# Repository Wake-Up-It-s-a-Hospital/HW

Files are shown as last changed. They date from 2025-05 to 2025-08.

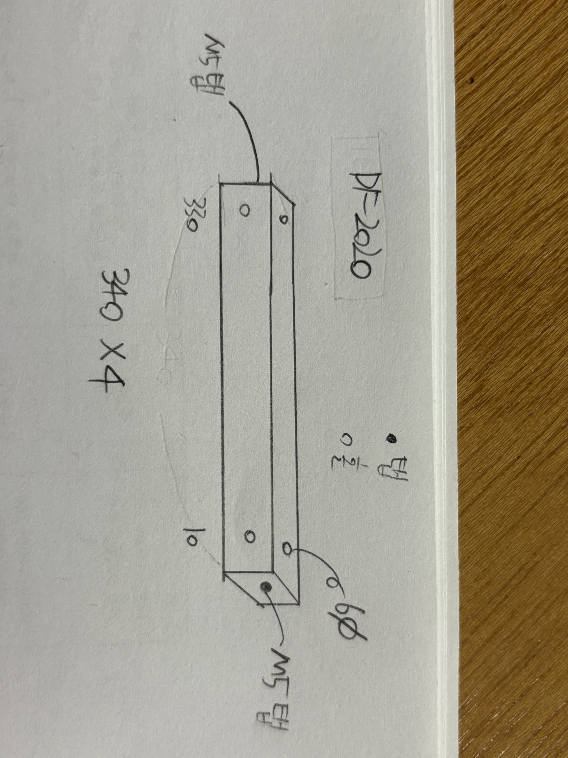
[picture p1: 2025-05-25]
프로파일/1번프로파일.jpg

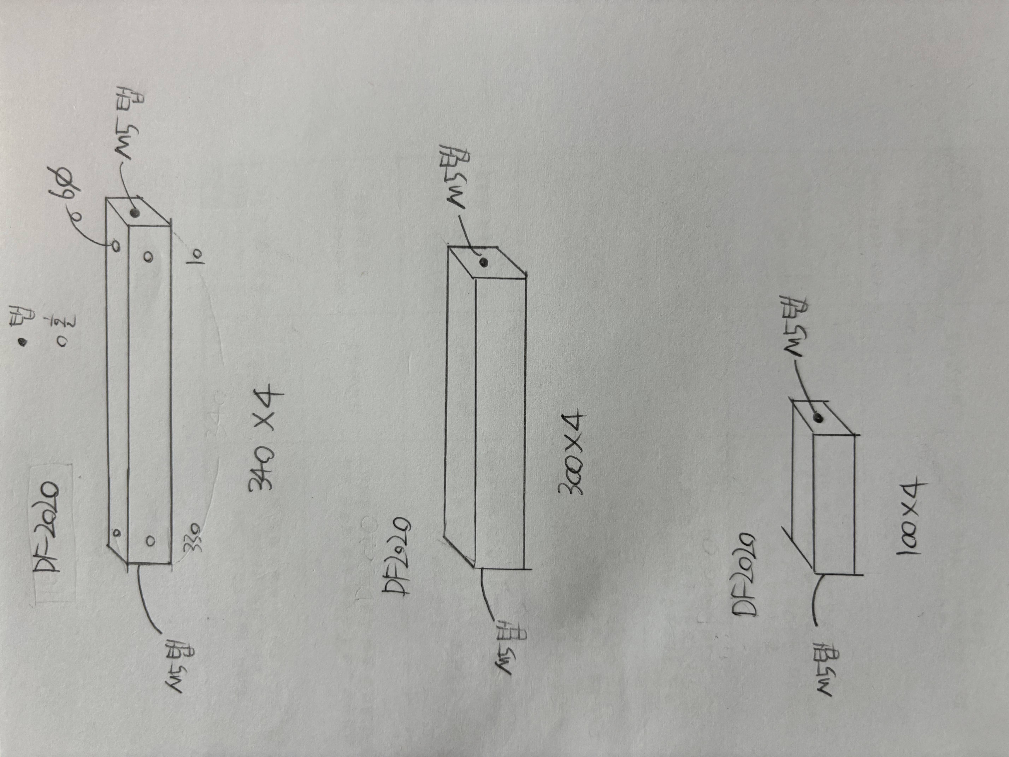
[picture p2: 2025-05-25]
프로파일/전체 프로파일들 (2).jpg

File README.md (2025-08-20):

# Hardware




##### 환자 추종 스마트 링거 폴대의 PCB 및 HW 설계를 담당하는 레포지토리입니다.

_구동부, 손잡이부, 스마트 기능부에 해당하는 PCB 설계 및 회로도와 각각의 부분에 해당하는 HW 설계 및 3D modeling 등을 설계하였습니다._

본 레포지토리는 **2025년 한국공학대학교 종합설계 (캡스톤디자인) 프로젝트**와 **한이음 프로젝트**의 지원을 받아 개발되고 있습니다.

N|Solid (https://nodesource.com/products/nsolid)

---
### ✅ 현재까지 완성한 Hardware

#### :diamond_shape_with_a_dot_inside: 1. 구동부 부분의 프로파일 및 아크릴 설계 도면

- 정육각형 구동부 상자의 모서리 역할인 프로파일 도면

- 정육각형 구동부 상자의 면 역할인 아크릴 설계 도면
  - 각종 PCB, 소자, 배터리, 폴대 장착에 맞추어 타공

#### :diamond_shape_with_a_dot_inside: 2.  PCB 설계 도면

- 구동부, 손잡이부, 스마트 기능부
 
- 각각 KiCAD를 사용해서 제작
  - 별칭
    - 구동부 : 1층
    - 손잡이부 : 2층
    - 카메라부 : 3층
    - 스마트 기능부 : 4층
    - 스마트 웨어러블 기기 : 시계부
-  2층* 을 제외한 모든 PCB 는 KiCAD 버전 9.0으로 작성됨.
  
-  2층은 KiCAD 8.0 버전으로 작성됨.

- connector는 모두 molex 5264(수), 5267(암)을 사용함.
- 전원 connector는 5557(수), 5566(암)을 사용함.

#### :diamond_shape_with_a_dot_inside: 3. 3D Modeling
- STM32로부터 수신한 데이터 패킷(lost 상황, 자동/수동 모드)을 AWS 서버로 전송

- NodeRed연동된 스마트 웨어러블 기기와 실시간으로 통신하여 경고 알림 제공

#### :diamond_shape_with_a_dot_inside: 4. 자동 / 수동 모드 전환 기능
- 링거 폴대 하부의 버튼 입력을 통해 자동 ↔ 수동 모드 전환 가능

---
## Data Flow

```mermaid
sequenceDiagram
    participant ESP32_LEFT as ESP32 (HUSKY_LEFT)
    participant STM32
    participant ESP32_RIGHT as ESP32 (HUSKY_RIGHT)

    ESP32_LEFT->>STM32: θ (조향각), currentMode (자동/수동)
    STM32->>ESP32_RIGHT: SoC (State of Charge)
    STM32->>ESP32_LEFT: lost 상태, SoC (State of Charge)

```

## 📁 주요 버전 디렉토리 구조

```
Patient-Recognition/
├── latest version/
|  ├──HUSKY_LEFT_AWS_V1_0       #ESP32 LEFT 
|  ├──HUSKY_RIGHT_WIFI_V1_0     #ESP32 RIGHT
├── test version/
|  ├──remote_control0           #이전 버전 원격 조정
|  ├──remote_control1           #최신 버전 원격 조정
|  ├──remote_master             #STM32 측 구동부
├── previous version/
|  ├──HUSKY_SERVO_V2_0          # 이전 버전 (서보모터 사용 허스키 1개)
|  ├──HUSKY_SErVO_V3_0
```

---

## 설치 및 실행 방법

### 1. HUSKYLENS 펌웨어
1) Arduino IDE 설치
2) HUSKYLENS header file 설치
[HUSKYLENS 공식 문서](https://wiki.dfrobot.com/HUSKYLENS_V1.0_SKU_SEN0305_SEN0336#target_6)

**헤더 파일 오류시**

HuskyLensProtocolCore.C에서

    uint8_t* husky_lens_protocol_write_begin()
    {
        return &send_buffer;
    }

에서 return 값 변경(ESP32와의 호환성 문제)

    uint8_t* husky_lens_protocol_write_begin()
    {
        return send_buffer;
    }

3) `latest version` 폴더 열어 LEFT, RIGHT 선택
4) 해당 코드에 맞는 좌우 HUSKYLENS 연결
5) 기본 HW 연결 세팅 확인 및 펌웨어 업로드

> :electric_plug: 기본 HW 세팅 회로도



### 2. HUSKYLENS HW 장착
 1) HW Repository Camera Cover file 열기
 2) HW Repository Camera Clamp file 열기
 3) HW Repository 2ndfloor_pole_bracket 열기
 4) HW Repository 2ndfloor_pole_bracket_RIGHT 열기
 5) 3D 프린터로 해당 Cover 인쇄 (2EA)
 6) 3D 프린터로 해당 Clamp 인쇄 (1EA)
 7) 3D 프린터로 해당 bracket, brackeet_RIGHT 인쇄 (각 1EA)
 8) 좌우 구분하여 LEFT, RIGHT HUSKYLENS 장착

 ### 3. STM32와의 통신선 연결 (UART)
 1) STM32와의 UART (TX, RX) 연결
 2) STM32와는 통신선 교차 연결

> :electric_plug: 기본 통신선 세팅 회로도
    

## :iphone: 주요 기능

### 환자 인식
 - 허스키렌즈를 통한 환자 인식
 - ID 별 인식 구별을 통한 다른 환자의 환자복 인식 방지 기능
 - 허스키렌즈 2개를 통한 조향각 매핑

 ### 데이터 통신
 - STM32와의 주요 factor 통신 (UART)
 - 스마트 웨어러블 기기와의 통신 (AWS NodeRed)

 ## :pushpin:  TODO (예정 기능)

 - [x] pull-up 저항 PCB 업데이트
 - [x] beacon 을 활용한 폴대 사용자의 위치 추정 기술
 - [x] 왼쪽 허스키 교체 (부품)
 - [x] ???

---
 ## 🤝 기여하기

1. 이 저장소를 포크합니다
2. 새로운 기능 브랜치를 생성합니다 (`git checkout -b feature/AmazingFeature`)
3. 변경사항을 커밋합니다 (`git commit -m 'Add some AmazingFeature'`)
4. 브랜치에 푸시합니다 (`git push origin feature/AmazingFeature`)
5. Pull Request를 생성합니다

---

## 📝 라이선스

이 프로젝트는 [MIT License](LICENSE)를 따릅니다. 자유롭게 사용, 수정, 배포하셔도 좋습니다.

---

## 📬 연락처

- ✉️ dy061932@tukorea.ac.kr  (학교)
- ✉️ dy353020@naver.com      (개인)

---

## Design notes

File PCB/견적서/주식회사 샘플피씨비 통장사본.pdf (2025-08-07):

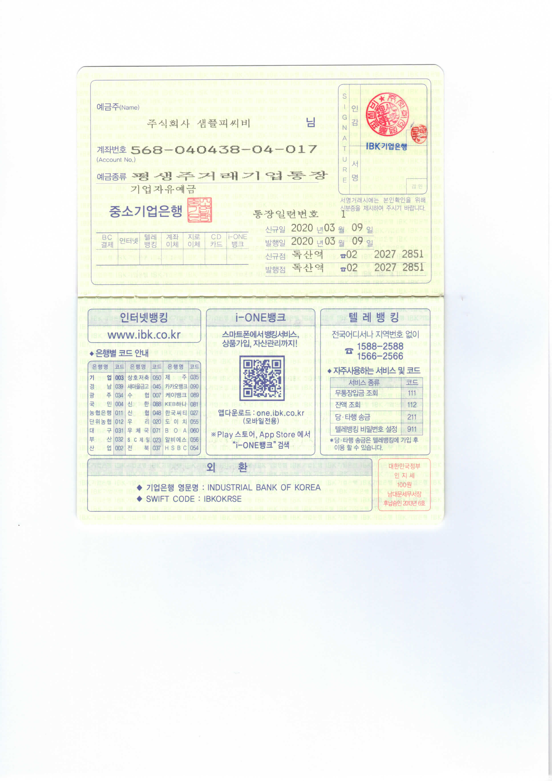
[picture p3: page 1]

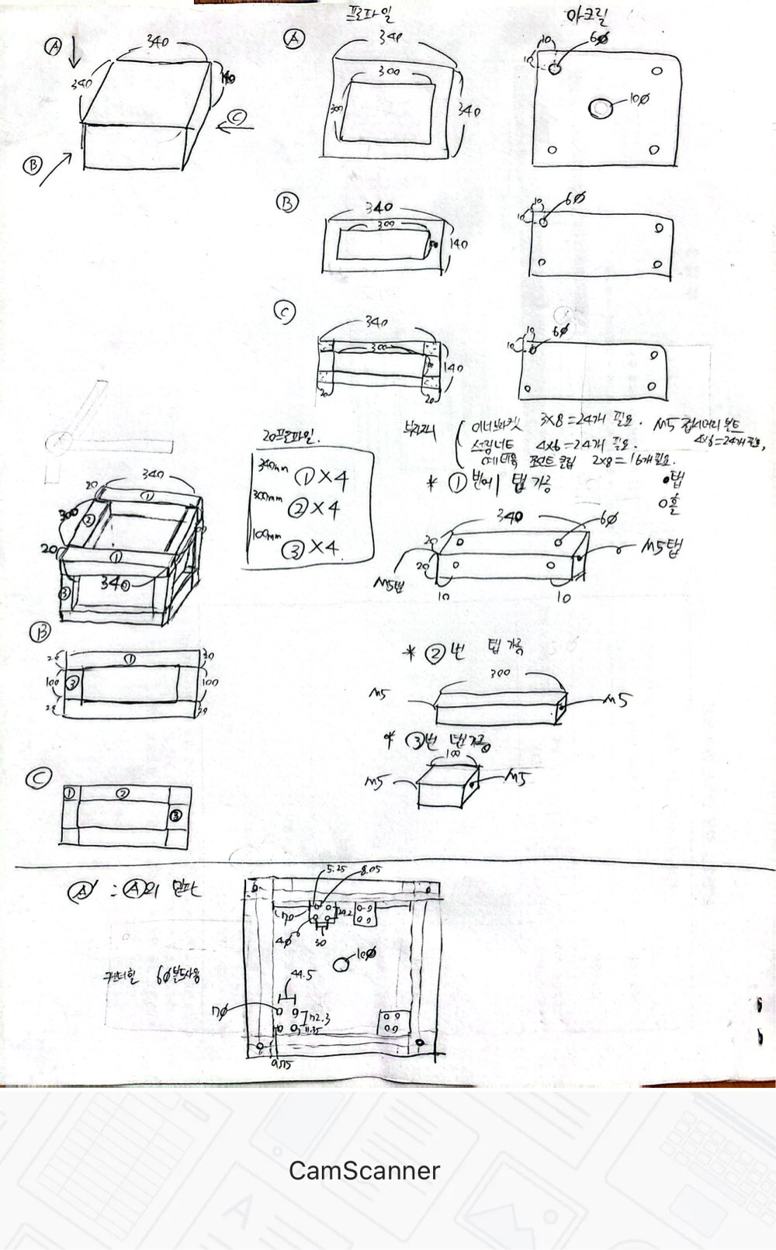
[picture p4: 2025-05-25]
전체설계도.jpg

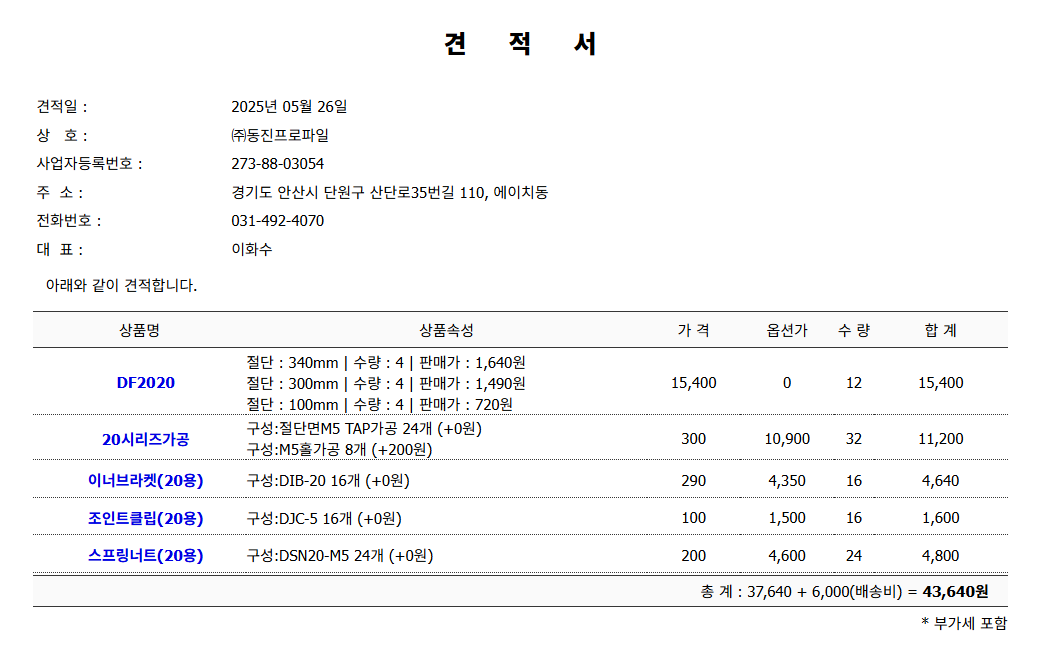
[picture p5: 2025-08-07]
프로파일견적서.png

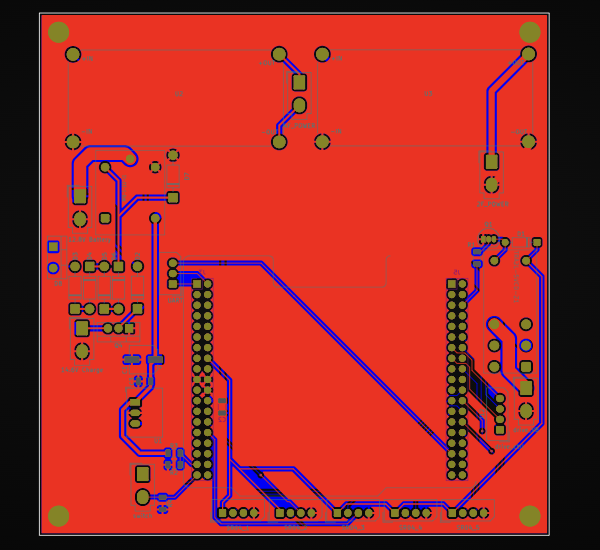
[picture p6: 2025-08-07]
3D modeling/smart wearable device/견적서/1층 pcb 설계도.png

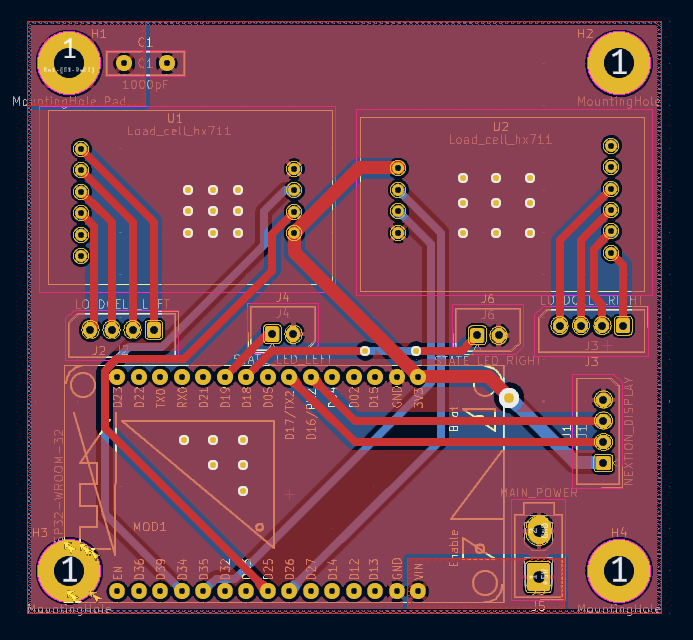
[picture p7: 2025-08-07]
PCB/견적서/4층 pcb 설계도.png

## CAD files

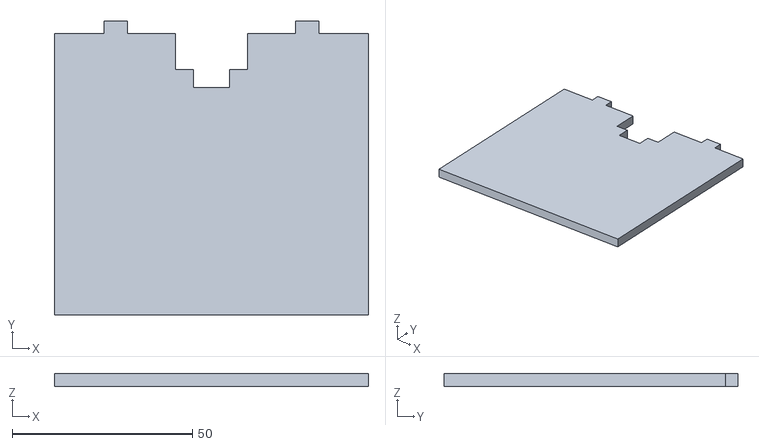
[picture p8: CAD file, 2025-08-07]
3D modeling/2층 PCB 오른쪽/2ndfloor_pole_bracket_RIGHT COVER.stl
87.0 x 81.5 x 3.50

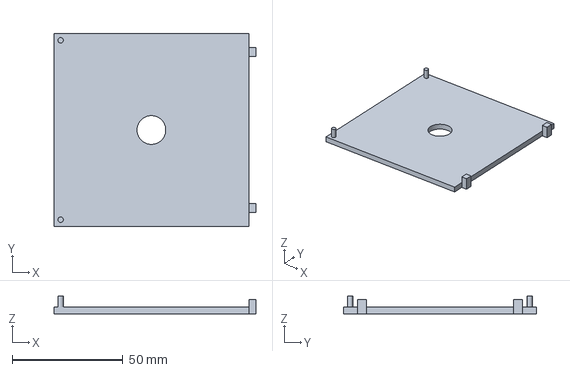
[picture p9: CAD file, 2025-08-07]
3D modeling/2층 모델링/2ndfloor_pole_bracket 뚜껑.3mf
91.2 x 87.0 x 8.00 mm

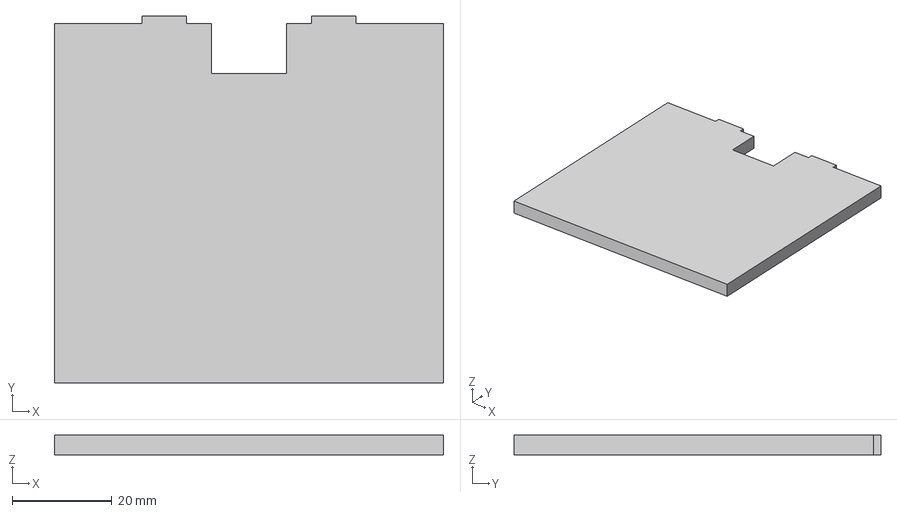
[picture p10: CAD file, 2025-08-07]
3D modeling/4층 모델링/4thfloor_bracket 뚜껑.3mf
78.0 x 73.5 x 4.00 mm

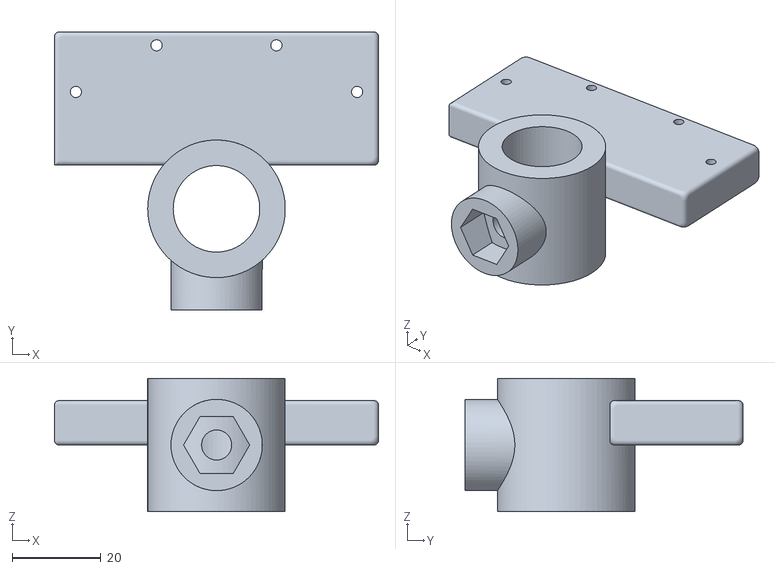
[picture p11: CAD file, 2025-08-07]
3D modeling/camera clamp/Camera Clamp v1.stl
73.0 x 62.6 x 30.0

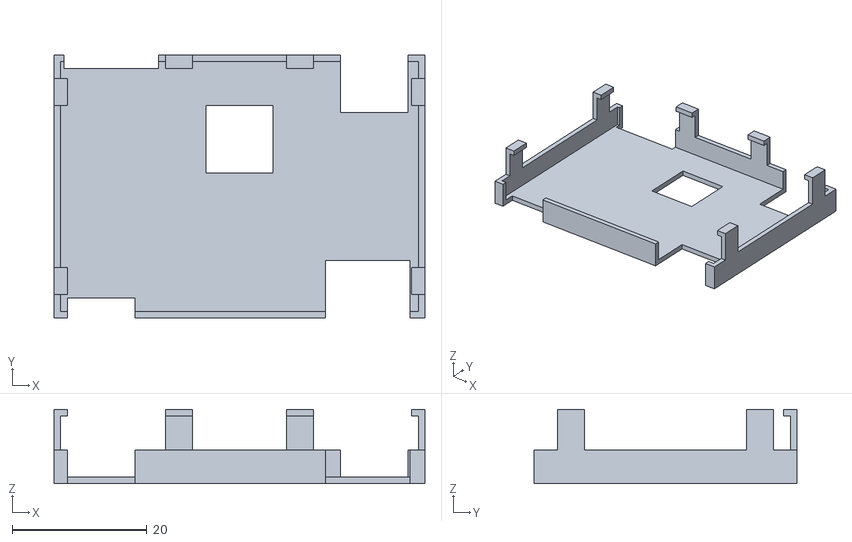
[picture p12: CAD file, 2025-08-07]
3D modeling/camera cover/huskylens_cover.stl
55.0 x 39.0 x 11.0

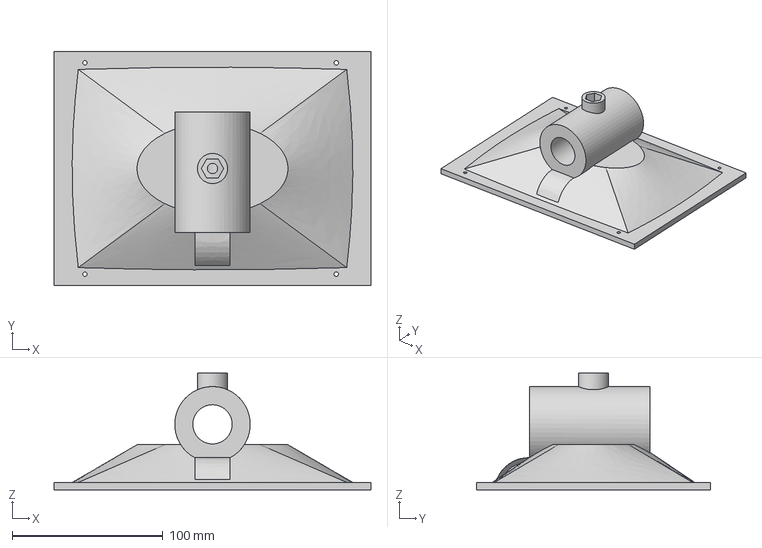
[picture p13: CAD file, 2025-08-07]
3D modeling/display clamp/Display_bracket v3.step
210.0 x 155.0 x 77.5 mm

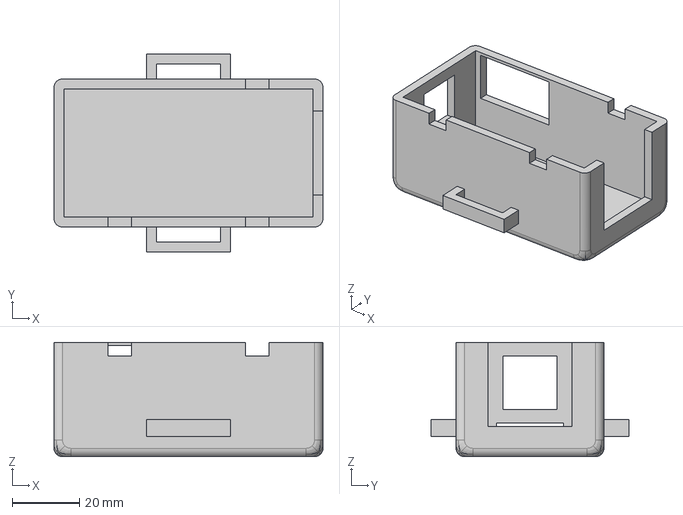
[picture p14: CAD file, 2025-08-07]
3D modeling/smart wearable device/new_watch_body_v2.step
80.0 x 59.0 x 34.0 mm

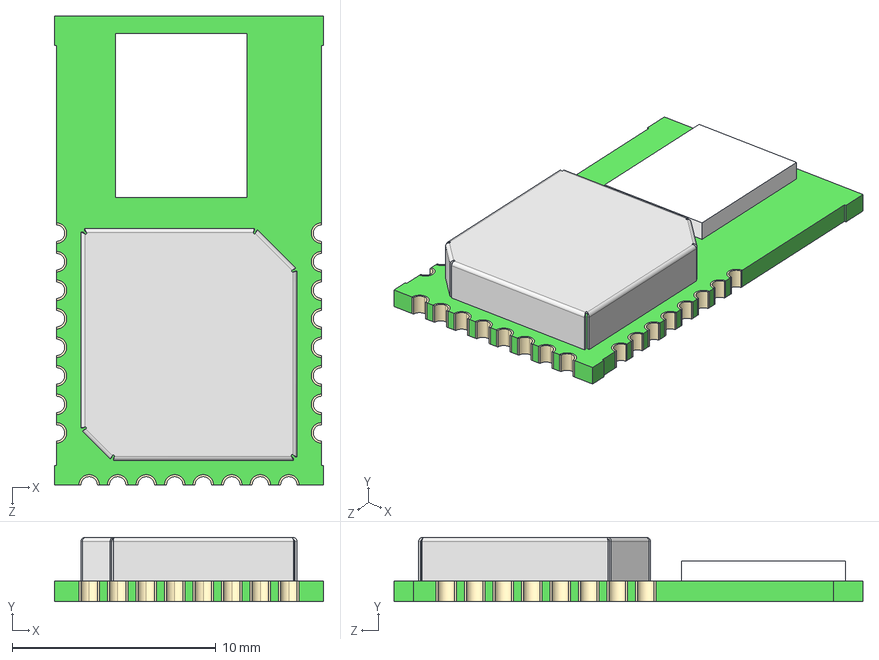
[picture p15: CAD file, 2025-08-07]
PCB/DWM1000/DWM1000.step
13.2 x 3.15 x 23.0 mm

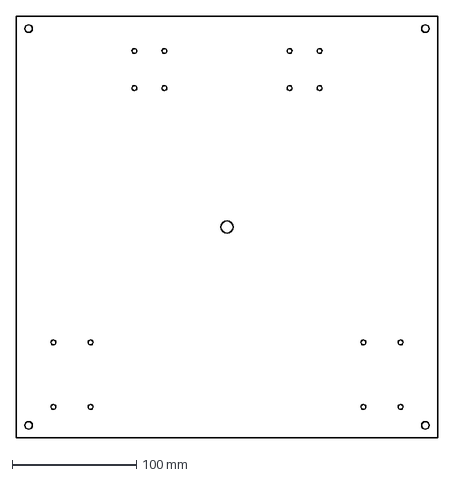
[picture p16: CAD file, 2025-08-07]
아크릴/A''_BALL_CASTER v1.dxf
340.0 x 340.0 mm

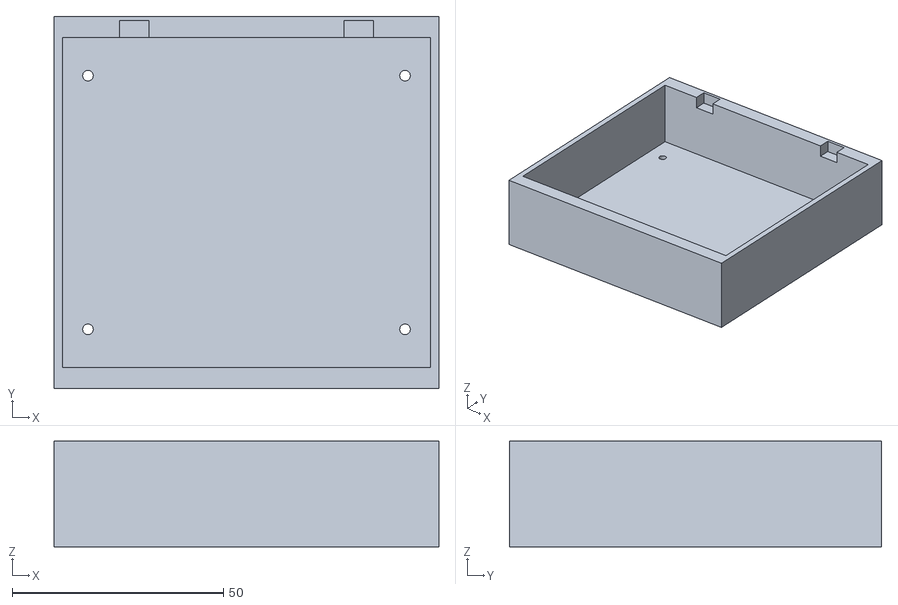
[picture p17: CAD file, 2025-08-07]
3D modeling/2층 PCB 오른쪽/2ndfloor_pole_bracket_RIGHT PCB.stl
91.0 x 88.0 x 25.0

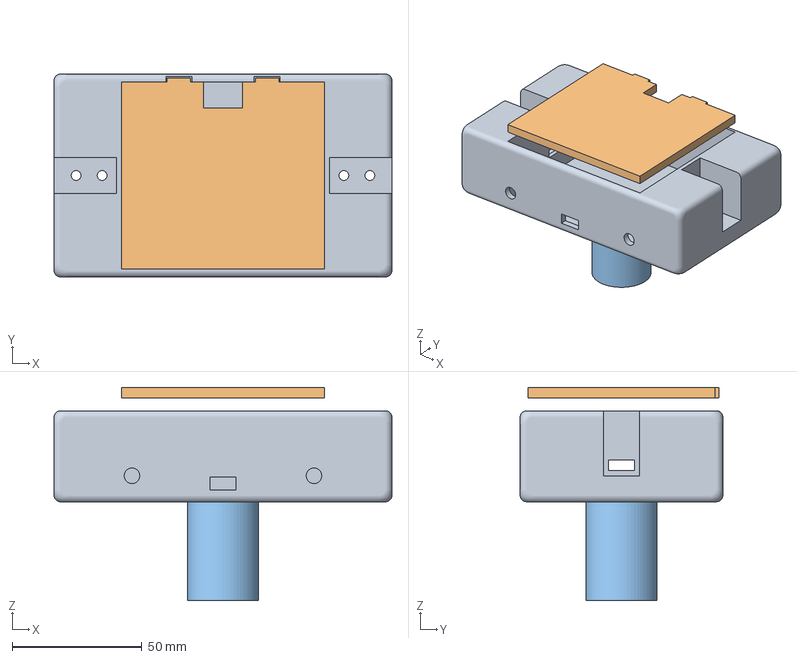
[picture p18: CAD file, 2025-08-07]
3D modeling/4층 모델링/4thfloor_bracket v3.3mf
130.0 x 78.0 x 82.0 mm
PCB + 로드셀 상자
뚜껑
원기둥

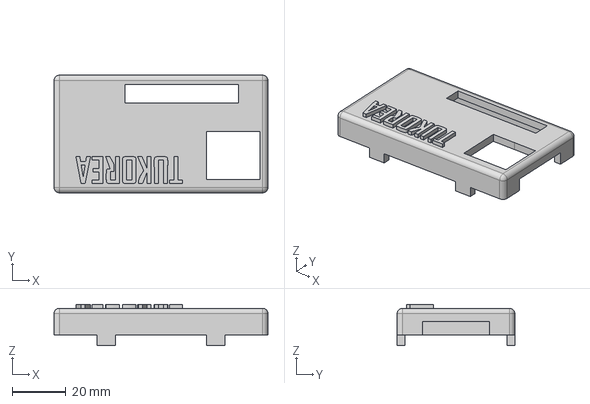
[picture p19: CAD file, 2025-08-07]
3D modeling/smart wearable device/new_watch_cover_v2.step
80.0 x 44.0 x 15.5 mm

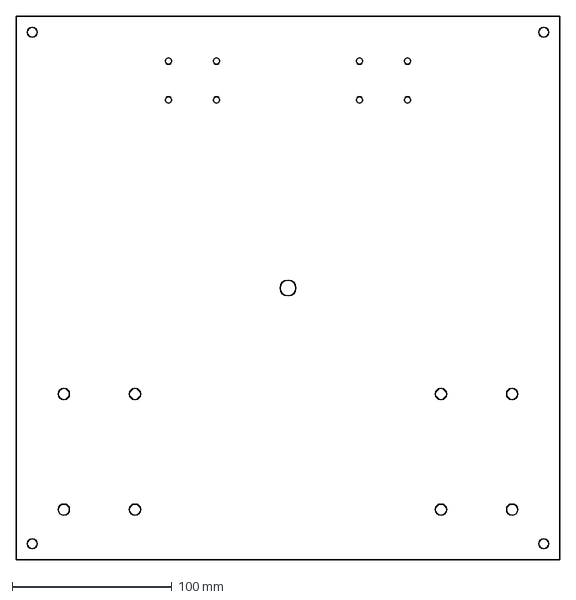
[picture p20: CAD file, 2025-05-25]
아크릴/A'.dxf
340.0 x 340.0 mm

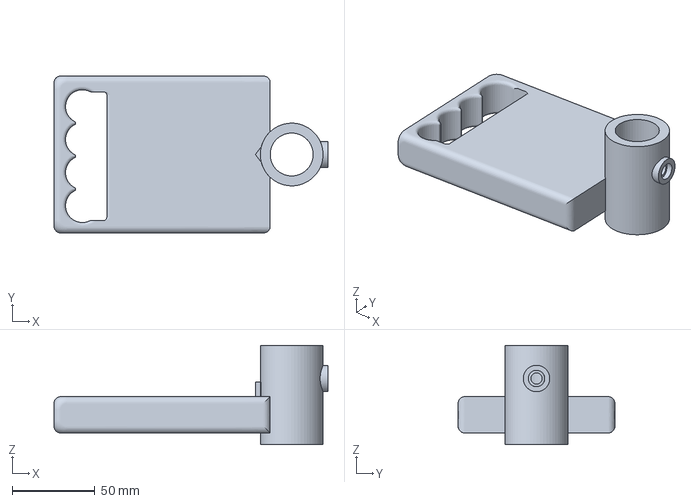
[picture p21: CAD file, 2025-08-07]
3D modeling/2층 모델링/2ndfloor_pole_bracket v12.3mf
166.0 x 95.0 x 60.0 mm

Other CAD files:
3D modeling/2층 모델링/2ndfloor_pole_bracket 뚜껑(reverse).gcode.3mf
3D modeling/4층 모델링/4thfloor_bracket 본체.3mf
3D modeling/2층 모델링/2ndfloor_pole_bracket v12.stl
3D modeling/2층 모델링/2ndfloor_pole_bracket 뚜껑.stl
3D modeling/4층 모델링/4thfloor_bracket v3.dxf
3D modeling/4층 모델링/4thfloor_bracket 뚜껑.gcode.3mf
3D modeling/4층 모델링/4thfloor_bracket 본체.dxf
3D modeling/4층 모델링/4thfloor_bracket 본체.gcode.3mf
3D modeling/display clamp/Display_bracket v3.3mf
아크릴/A.dxf
아크릴/B.dxf

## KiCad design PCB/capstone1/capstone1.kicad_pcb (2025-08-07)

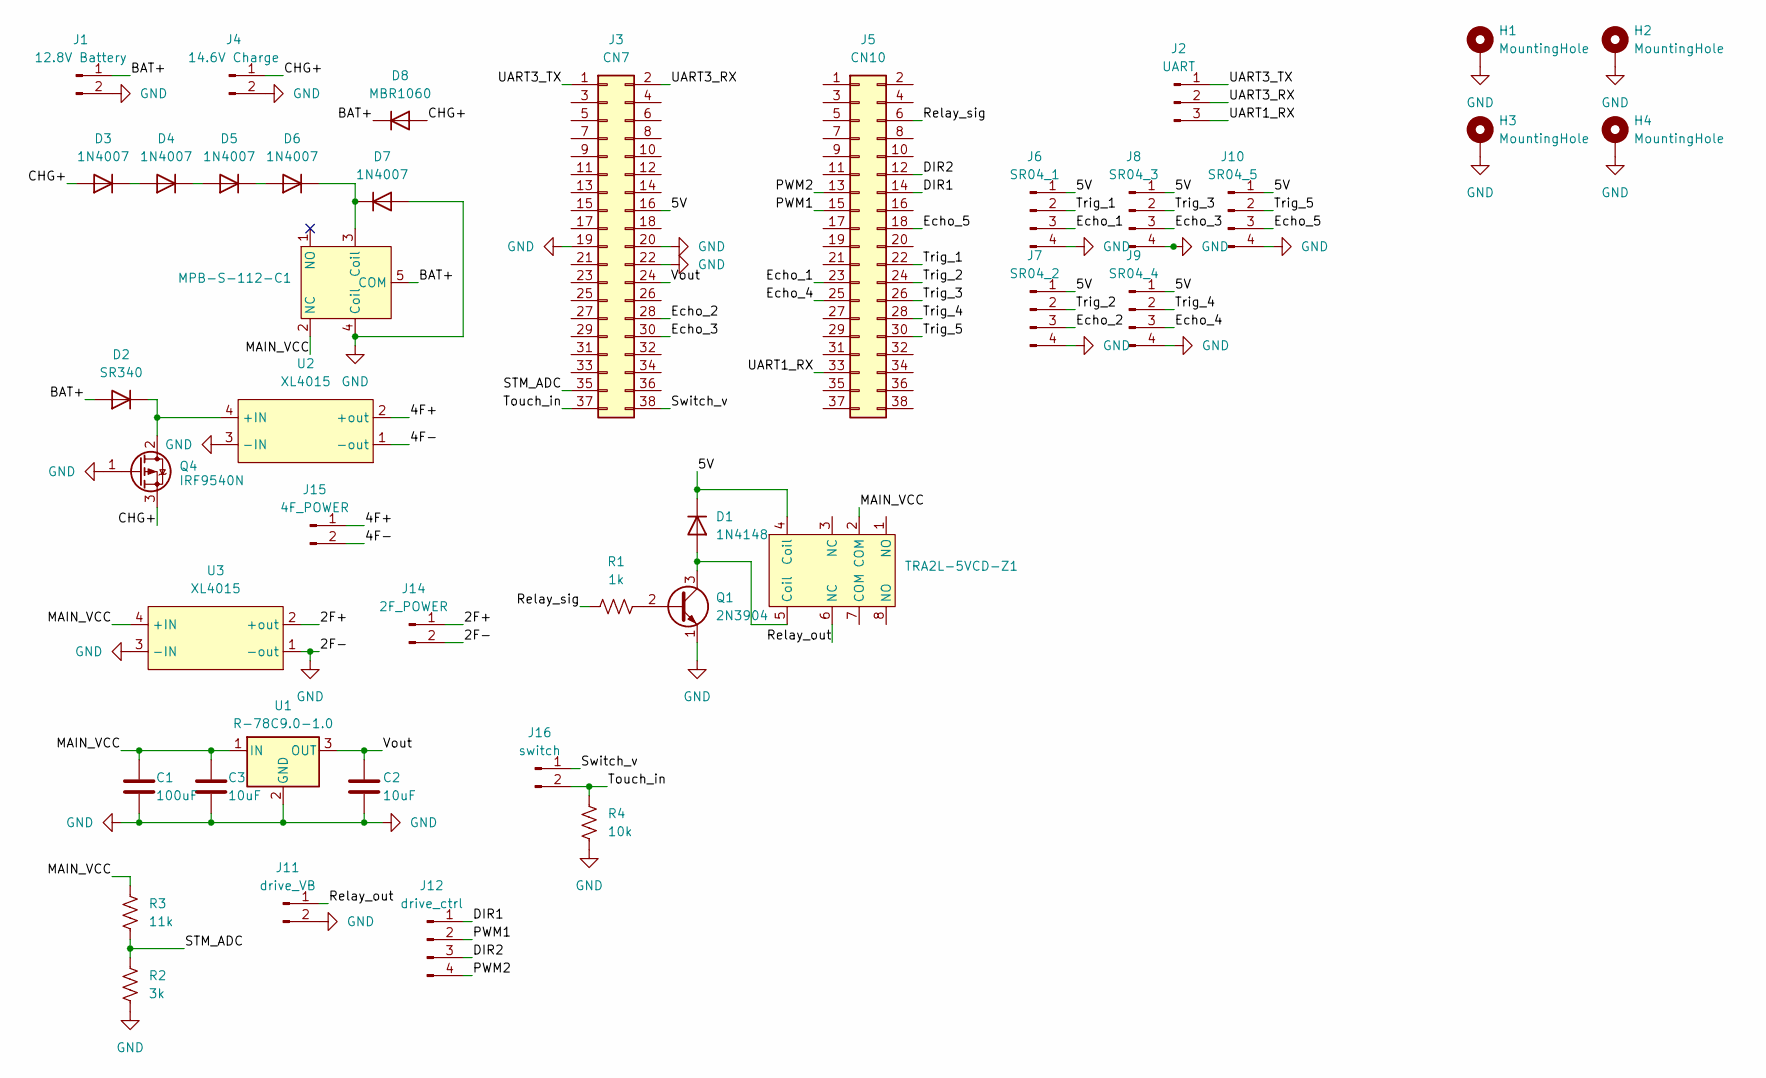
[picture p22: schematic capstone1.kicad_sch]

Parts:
C1: 100uF; CP_Elec_6.3x5.3
C2, C3: 10uF; C_1206_3216Metric
D1: 1N4148; D_DO-35_SOD27_P7.62mm_Horizontal
D2: SR340; D_DO-41_SOD81_P10.16mm_Horizontal
D3, D4, D5, D6, D7: 1N4007; D_DO-41_SOD81_P10.16mm_Horizontal
D8: MBR1060; TO-220-2_Vertical
H1, H2, H3, H4: MountingHole; MountingHole_2.5mm_Pad
J1: 12.8V Battery; Molex_Mini-Fit_Jr_5566-02A_2x01_P4.20mm_Vertical
J2: UART; Molex_SPOX_5267-03A_1x03_P2.50mm_Vertical
J3: CN7; PinSocket_2x19_P2.54mm_Vertical
J4: 14.6V Charge; Molex_Mini-Fit_Jr_5566-02A_2x01_P4.20mm_Vertical
J5: CN10; PinSocket_2x19_P2.54mm_Vertical
J6: SR04_1; Molex_SPOX_5267-04A_1x04_P2.50mm_Vertical
J7: SR04_2; Molex_SPOX_5267-04A_1x04_P2.50mm_Vertical
J8: SR04_3; Molex_SPOX_5267-04A_1x04_P2.50mm_Vertical
J9: SR04_4; Molex_SPOX_5267-04A_1x04_P2.50mm_Vertical
J10: SR04_5; Molex_SPOX_5267-04A_1x04_P2.50mm_Vertical
J11: drive_VB; Molex_Mini-Fit_Jr_5566-02A_2x01_P4.20mm_Vertical
J12: drive_ctrl; Molex_SPOX_5267-04A_1x04_P2.50mm_Vertical
J14: 2F_POWER; Molex_Mini-Fit_Jr_5566-02A_2x01_P4.20mm_Vertical
J15: 4F_POWER; Molex_Mini-Fit_Jr_5566-02A_2x01_P4.20mm_Vertical
J16: switch; Molex_Mini-Fit_Jr_5566-02A_2x01_P4.20mm_Vertical
MPB-S-112-C1: MPB-S-112-C
Q1: 2N3904; TO-92_Inline
Q4: IRF9540N; TO-220-3_Vertical
R1: 1k; R_1206_3216Metric
R2: 3k; R_1206_3216Metric
R3: 11k; R_1206_3216Metric
R4: 10k; R_1206_3216Metric
TRA2L-5VCD-Z1: TRA2L-5VCD-Z
U1: R-78C9.0-1.0; Converter_DCDC_RECOM_R-78E-0.5_THT
U2, U3: XL4015

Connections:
/2F+: J14.1, U3.2 (+out)
/4F+: J15.1, U2.2 (+out)
/4F-: J15.2, U2.1 (-out)
/5V: D1.1 (K), J3.16, J6.1, J7.1, J8.1, J9.1, J10.1, TRA2L-5VCD-Z1.4 (Coil)
/BAT+: D2.2 (A), D8.1 (K), J1.1, MPB-S-112-C1.5 (COM)
/CHG+: D3.2 (A), D8.2 (A), J4.1, Q4.3 (S)
/DIR1: J5.14, J12.1
/DIR2: J5.12, J12.3
/Echo_1: J5.23, J6.3
/Echo_2: J3.28, J7.3
/Echo_3: J3.30, J8.3
/Echo_4: J5.25, J9.3
/Echo_5: J5.18, J10.3
/MAIN_VCC: C1.1, C3.1, MPB-S-112-C1.2 (NC), R3.1, TRA2L-5VCD-Z1.2 (COM), U1.1 (IN), U3.4 (+IN)
/PWM1: J5.15, J12.2
/PWM2: J5.13, J12.4
/Relay_out: J11.1, TRA2L-5VCD-Z1.6 (NC)
/Relay_sig: J5.6, R1.1
/STM_ADC: J3.35, R2.1, R3.2
/Switch_v: J3.38, J16.1
/Touch_in: J3.37, J16.2, R4.1
/Trig_1: J5.22, J6.2
/Trig_2: J5.24, J7.2
/Trig_3: J5.26, J8.2
/Trig_4: J5.28, J9.2
/Trig_5: J5.30, J10.2
/UART1_RX: J2.3, J5.33
/UART3_RX: J2.2, J3.2
/UART3_TX: J2.1, J3.1
/Vout: C2.1, J3.24, U1.3 (OUT)
GND: C1.2, C2.2, C3.2, D7.2 (A), H1.1, H2.1, H3.1, H4.1, J1.2, J3.19, J3.20, J3.22, J4.2, J6.4, J7.4, J8.4, J9.4, J10.4, J11.2, J14.2, MPB-S-112-C1.4 (Coil), Q1.1 (E), Q4.1 (G), R2.2, R4.2, U1.2 (GND), U2.3 (-IN), U3.1 (-out), U3.3 (-IN)
unnamed: D1.2 (A), Q1.3 (C), TRA2L-5VCD-Z1.5 (Coil)
unnamed: D2.1 (K), Q4.2 (D), U2.4 (+IN)
unnamed: D3.1 (K), D4.2 (A)
unnamed: D4.1 (K), D5.2 (A)
unnamed: D5.1 (K), D6.2 (A)
unnamed: D6.1 (K), D7.1 (K), MPB-S-112-C1.3 (Coil)
unnamed: Q1.2 (B), R1.2

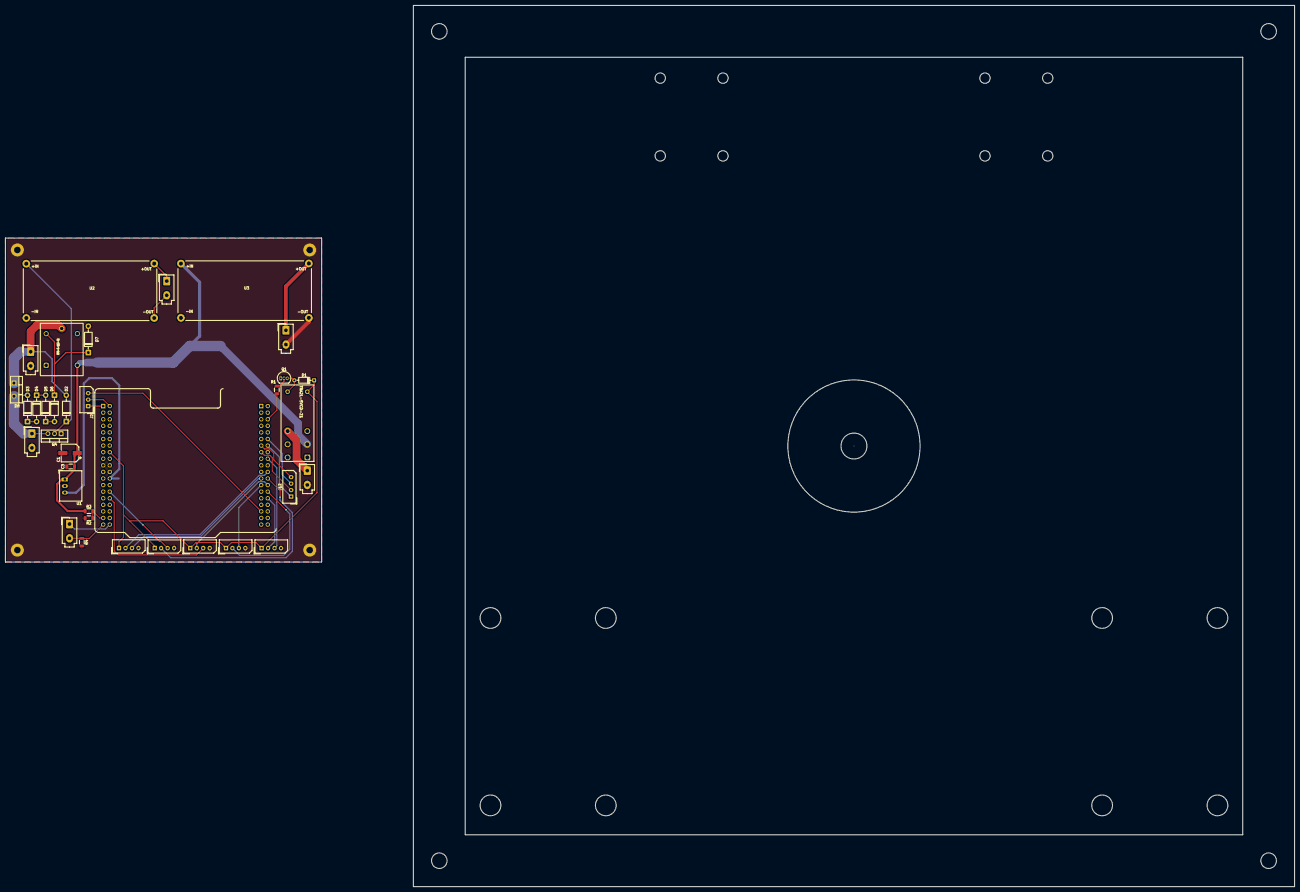
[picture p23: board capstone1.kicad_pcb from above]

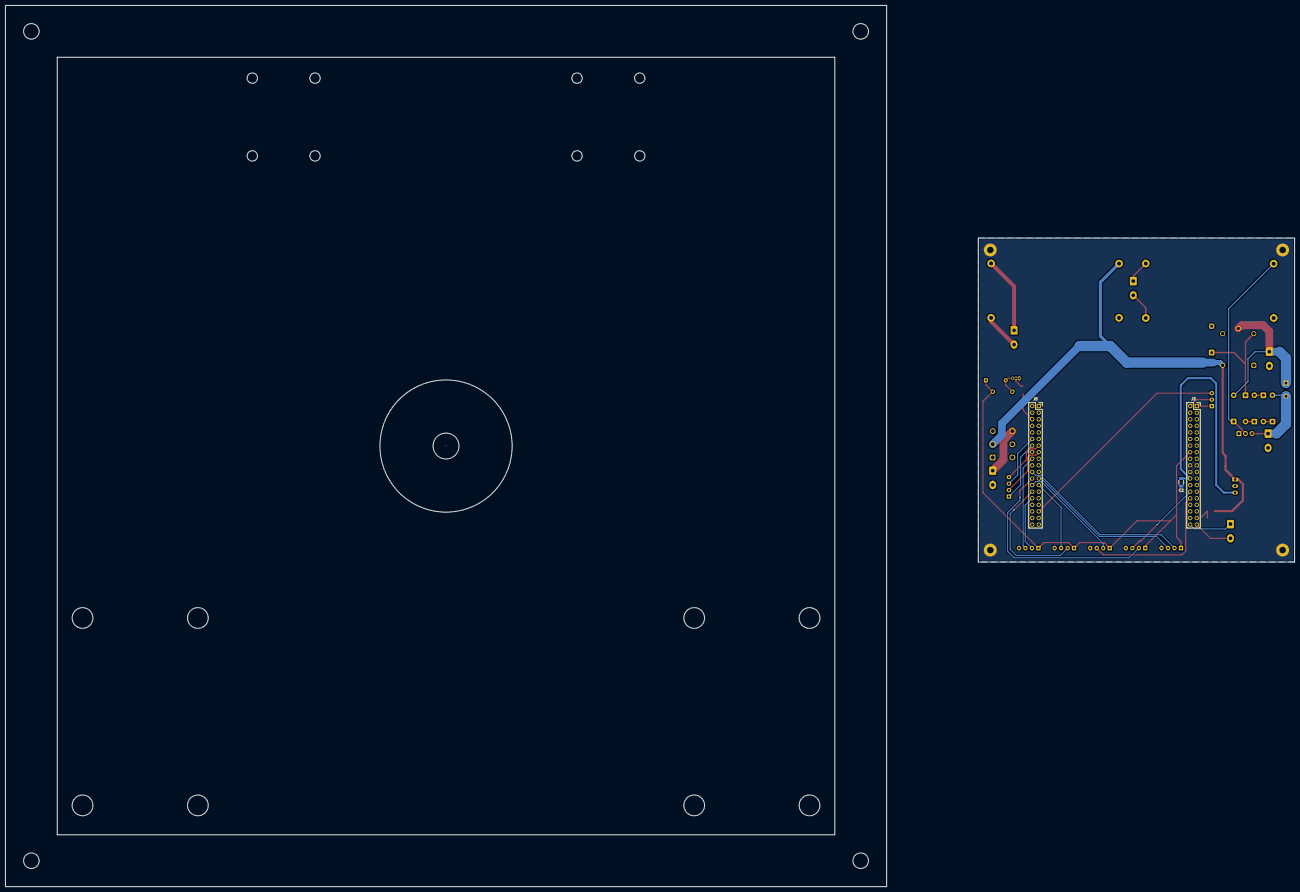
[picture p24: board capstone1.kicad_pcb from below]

Board: 2 copper layers, 122.0 x 125.0 mm, 41 parts (3 on the bottom side), 38 nets.

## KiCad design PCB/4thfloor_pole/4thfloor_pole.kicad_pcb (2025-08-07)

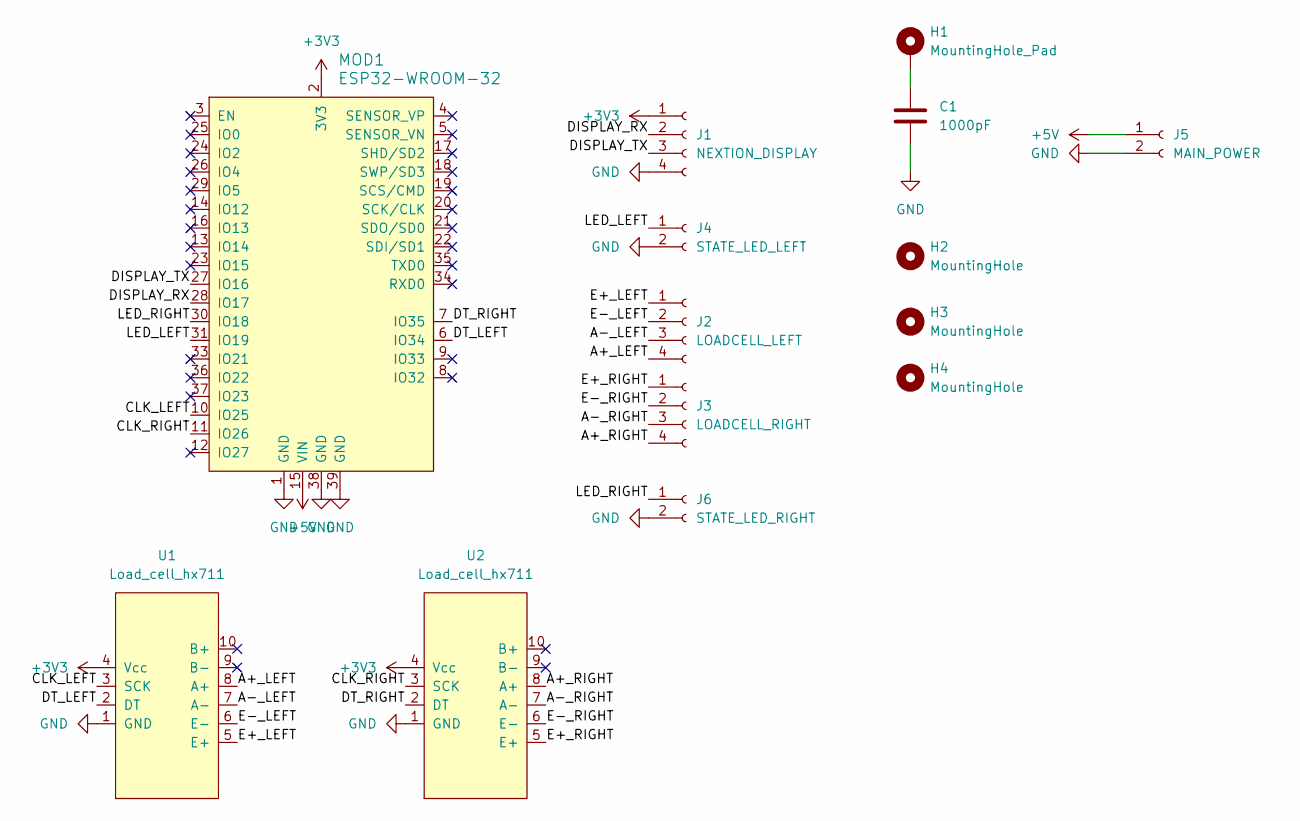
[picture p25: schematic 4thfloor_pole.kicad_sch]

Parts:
C1: 1000pF; C_Disc_D9.0mm_W2.5mm_P5.00mm
H1: MountingHole_Pad; MountingHole_3.5mm_Pad
H2, H3, H4: MountingHole; MountingHole_3.5mm_Pad
J1: NEXTION_DISPLAY; Molex_SPOX_5267-04A_1x04_P2.50mm_Vertical
J2: LOADCELL_LEFT; Molex_SPOX_5267-04A_1x04_P2.50mm_Vertical
J3: LOADCELL_RIGHT; Molex_SPOX_5267-04A_1x04_P2.50mm_Vertical
J4: STATE_LED_LEFT; Molex_SPOX_5267-02A_1x02_P2.50mm_Vertical
J5: MAIN_POWER; Molex_Mini-Fit_Jr_5566-02A_2x01_P4.20mm_Vertical
J6: STATE_LED_RIGHT; Molex_SPOX_5267-02A_1x02_P2.50mm_Vertical
MOD1: ESP32-WROOM-32; ESP32_new_modified; MPN ESP32-WROOM-32; Digi-Key_PN 1904-1010-1-ND
U1, U2: Load_cell_hx711; loadcell

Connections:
+3V3: J1.1, MOD1.2 (3V3), U1.4 (Vcc), U2.4 (Vcc)
+5V: J5.1, MOD1.15 (VIN)
/A+_LEFT: J2.4, U1.8 (A+)
/A+_RIGHT: J3.4, U2.8 (A+)
/A-_LEFT: J2.3, U1.7 (A-)
/A-_RIGHT: J3.3, U2.7 (A-)
/CLK_LEFT: MOD1.10 (IO25), U1.3 (SCK)
/CLK_RIGHT: MOD1.11 (IO26), U2.3 (SCK)
/DISPLAY_RX: J1.2, MOD1.28 (IO17)
/DISPLAY_TX: J1.3, MOD1.27 (IO16)
/DT_LEFT: MOD1.6 (IO34), U1.2 (DT)
/DT_RIGHT: MOD1.7 (IO35), U2.2 (DT)
/E+_LEFT: J2.1, U1.5 (E+)
/E+_RIGHT: J3.1, U2.5 (E+)
/E-_LEFT: J2.2, U1.6 (E-)
/E-_RIGHT: J3.2, U2.6 (E-)
/LED_LEFT: J4.1, MOD1.31 (IO19)
/LED_RIGHT: J6.1, MOD1.30 (IO18)
GND: C1.2, J1.4, J4.2, J5.2, J6.2, MOD1.1 (GND), MOD1.38 (GND), MOD1.39 (GND), U1.1 (GND), U2.1 (GND)
unnamed: C1.1, H1.1

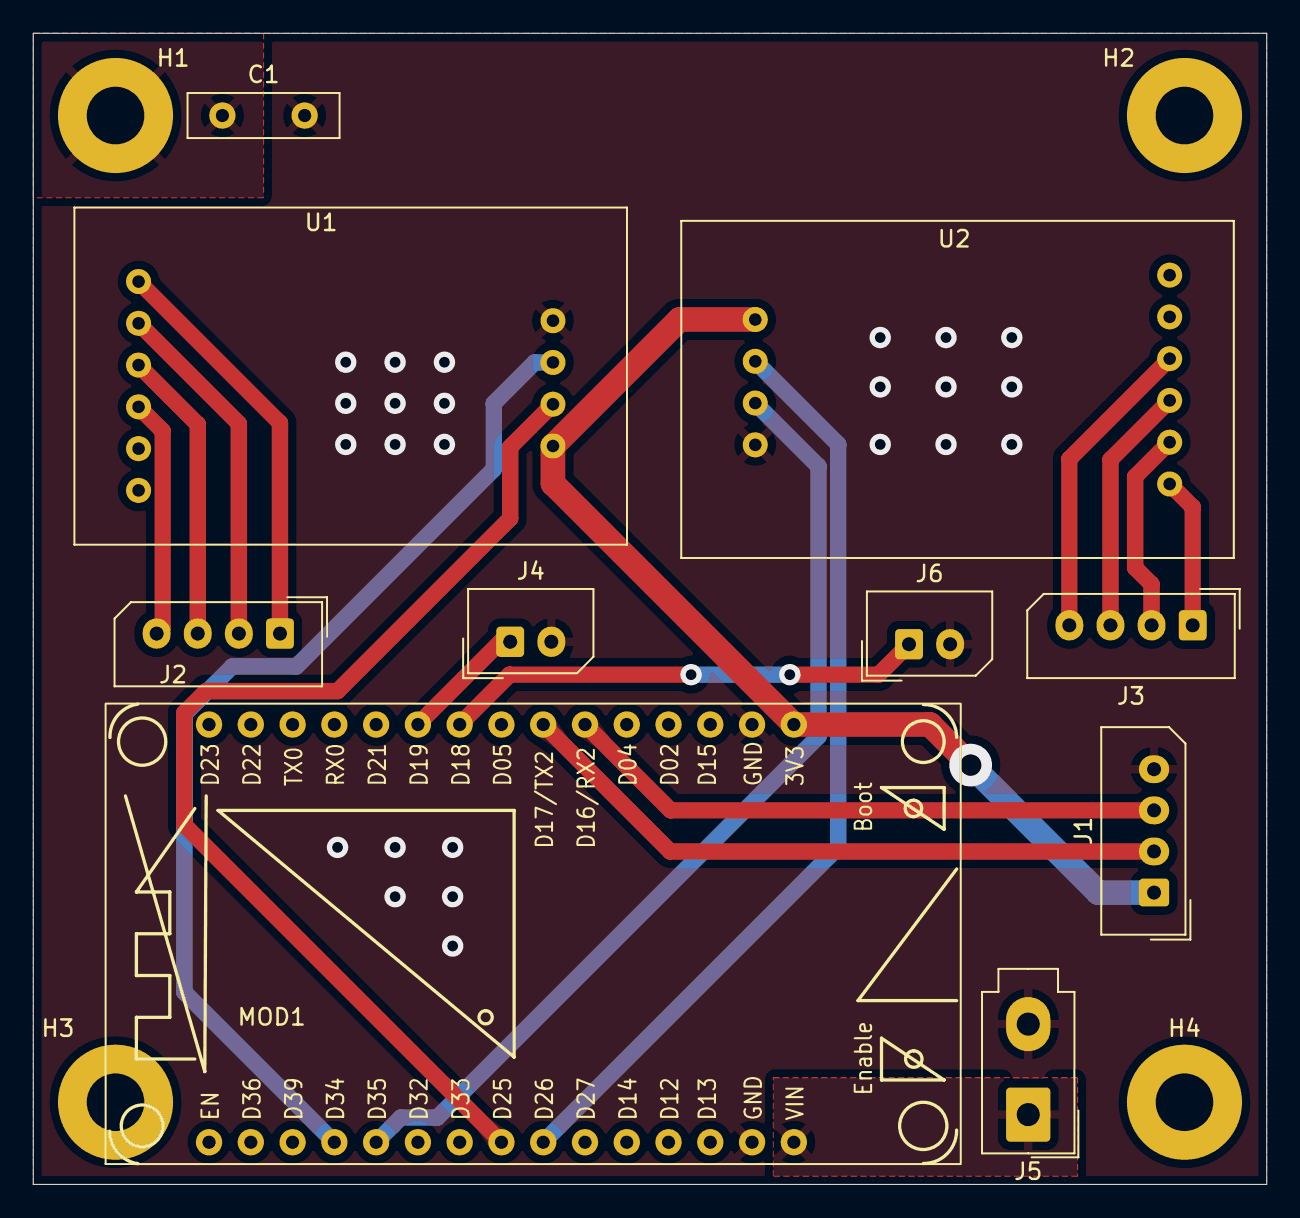
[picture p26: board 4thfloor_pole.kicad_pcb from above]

Board: 2 copper layers, 75.0 x 70.0 mm, 14 parts (0 on the bottom side), 20 nets.

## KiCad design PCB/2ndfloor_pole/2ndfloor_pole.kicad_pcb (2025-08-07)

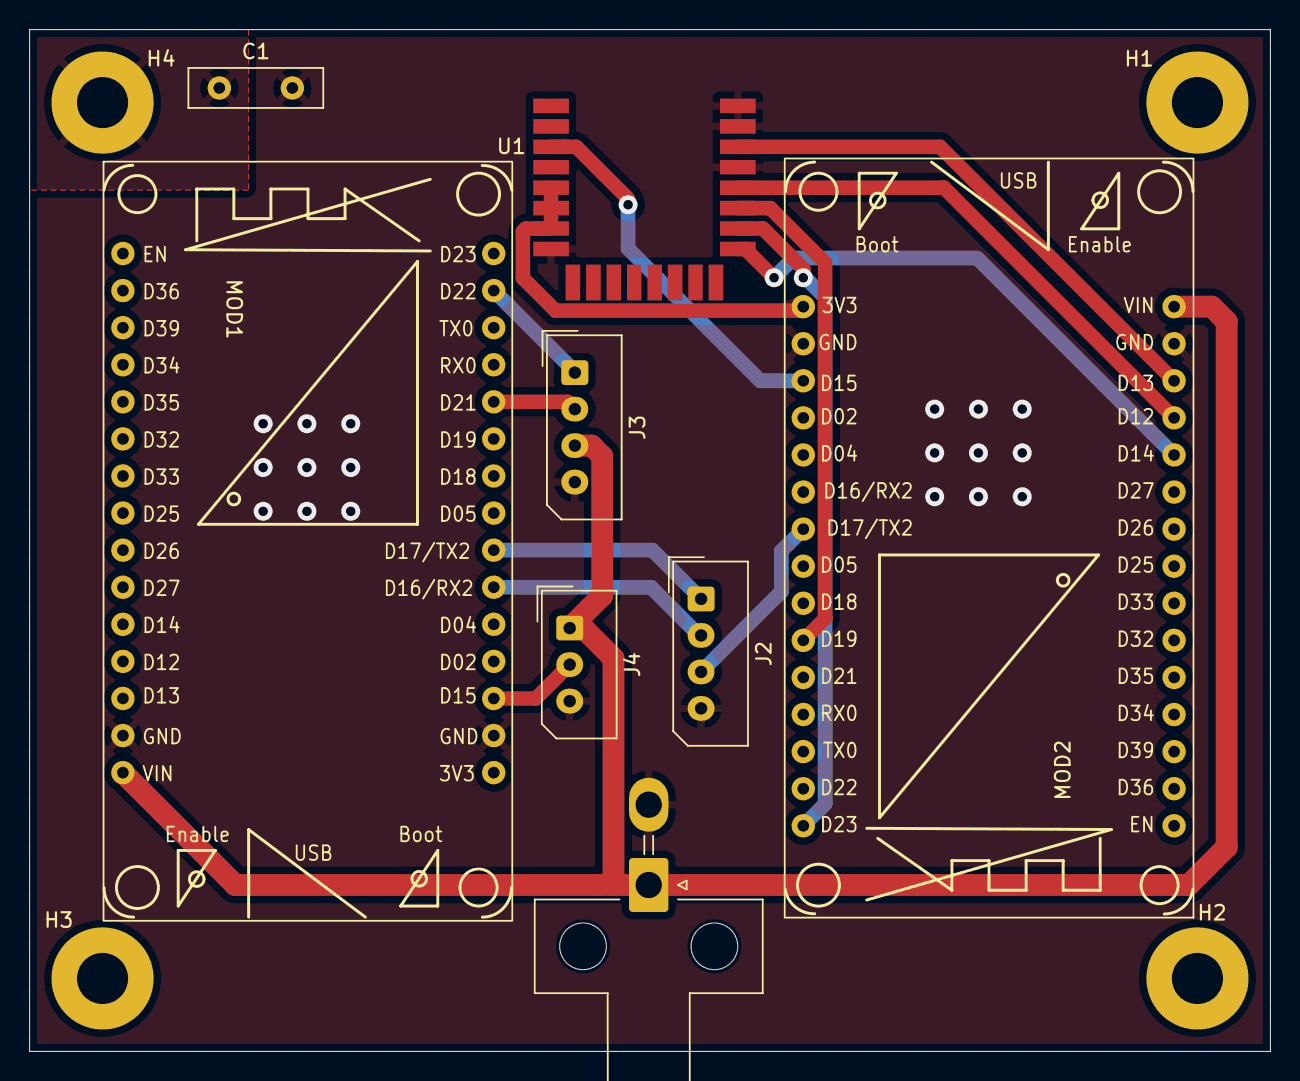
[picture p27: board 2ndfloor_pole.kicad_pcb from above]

Board: 2 copper layers, 85.0 x 70.0 mm, 12 parts (0 on the bottom side), 16 nets.

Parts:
C1: 1000pF; C_Disc_D9.0mm_W2.5mm_P5.00mm
H1, H2, H3: MountingHole; MountingHole_3.5mm_Pad
H4: MountingHole_Pad; MountingHole_3.5mm_Pad
J1: MAIN_POWER; Molex_Mini-Fit_Jr_5569-02A1_2x01_P4.20mm_Horizontal
J2: STM32<->ESP32-HUSKYLENS; Molex_SPOX_5267-04A_1x04_P2.50mm_Vertical
J3: HUSYYLENS; Molex_SPOX_5267-04A_1x04_P2.50mm_Vertical
J4: Servo(MG-90S); Molex_SPOX_5267-03A_1x03_P2.50mm_Vertical
MOD1: ESP32 - HUSKYLENS; ESP32_new
MOD2: ESP-UWB; ESP32_new
U1: DWM1000; XCVR_DWM1000

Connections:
+3.3V: MOD2.2 (3V3), U1.5 (VDDAON), U1.6 (VDD3V3@1), U1.7 (VDD3V3@2)
+5V: J1.1, J3.3, J4.1, MOD1.15 (VIN), MOD2.15 (VIN)
/CLK: MOD2.14 (IO12), U1.20 (SPICLK)
/CS: MOD2.13 (IO14), U1.17 (SPICSN)
/HUSKY_RX: J2.2, MOD1.27 (IO16)
/HUSKY_TX: J2.1, MOD1.28 (IO17)
/IRQ: MOD2.16 (IO13), U1.22 (IRQ/GPIO8)
/MISO: MOD2.31 (IO19), U1.19 (SPIMISO)
/MOSI: MOD2.37 (IO23), U1.18 (SPIMOSI)
/PWM_PIN: J4.2, MOD1.23 (IO15)
/RST: MOD2.23 (IO15), U1.3 (RSTN)
/SCL: J3.1, MOD1.36 (IO22)
/SDA: J3.2, MOD1.33 (IO21)
/UWB_TX: J2.3, MOD2.28 (IO17)
GND: C1.2, J1.2, J2.4, J3.4, J4.3, MOD1.1 (GND), MOD2.1 (GND), U1.8 (VSS@1), U1.21 (VSS@3), U1.23 (VSS@4), U1.24 (VSS@5)
unnamed: C1.1, H4.1

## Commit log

2025-05-25 아크릴 및 프로파일 설계도면&파일
    [A'.dxf, A.dxf, B.dxf]
2025-08-07 HW 부 최종 업데이트
    파일 최신화
    [2ndfloor_pole-B_Cu.gbr, 2ndfloor_pole-B_Mask.gbr, 2ndfloor_pole-B_Paste.gbr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]
2025-08-13 초기 업데이트

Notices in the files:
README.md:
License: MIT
